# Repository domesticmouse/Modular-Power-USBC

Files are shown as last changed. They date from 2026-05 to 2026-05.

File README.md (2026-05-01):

# Modular-Power-USBC

## Project Overview
This project provides a compact, high-efficiency power solution for modular electronics (such as Eurorack synthesizers or analog prototyping boards). It converts standard **5V USB-C power** into clean, dual **±12V rails**.

### Key Features
- **USB-C Input:** Uses a power-only 6-pin receptacle for durability and simplicity.
- **Dual Rail Output:** Provides ±12V at up to 83mA per rail (2W total).
- **Comprehensive Protection:** Features overcurrent, reverse polarity, and back-drive protection.
- **Controlled Startup:** Integrated load switch with a physical toggle for safe power-up.
- **Indicator LEDs:** Visual confirmation for both positive and negative rails.

### Main Technologies
- **EDA Tool:** KiCad (Project files version 20260306, KiCad 10.0 or newer).
- **Major Components:**
  - **DC-DC Converter:** `A0512S-2WR2` (Isolated 2W module).
  - **Ideal Diode:** `LM66100` (Reverse polarity & back-drive protection).
  - **Load Switch:** `TPS22918` (Gated power control).
  - **Filtering:** Ferrite bead and 0805 SMD decoupling capacitors.
  - **Protection:** Resettable Polyfuse (`F1`).

## Circuit Architecture
The power path is designed for reliability and safety:

1.  **Input & Filtering:** 5V enters via `J1`. It is immediately protected by a Polyfuse and filtered by a Ferrite Bead to reduce high-frequency noise.
2.  **Polarity Protection:** An `LM66100` ideal diode provides extremely low-loss protection against reverse voltage on the input.
3.  **Gated Control:** The `TPS22918` load switch acts as the master gate. A physical SPDT slide switch (`SW1`) controls the enable pin, allowing the user to safely toggle the ±12V rails.
4.  **Isolated Conversion:** The `A0512S-2WR2` performs the heavy lifting, converting the 5V input to isolated ±12V outputs. This isolation helps prevent ground loops between the USB source and the analog circuitry.
5.  **Output Rail:** The dual rails are broken out to 2.54mm headers (`J2`, `J3`) for plugging into a breadboard.

## Directory Structure
- `Modular-Power-USBC.kicad_sch`: Main schematic file.
- `Modular-Power-USBC.kicad_pcb`: PCB layout file.
- `Modular-Power-USBC.pretty/`: Local footprint library for custom components.
- `ModularPower.kicad_sym`: Local symbol library.
- `production/`: Fabrication-ready files (Gerbers, BOM, Pick-and-Place).

## Project Status
- **Schematic:** Functional design complete.
- **ERC Status:** 1 Error (Pin 2 of PS1 not driven). Note: This is an ERC artifact due to a missing `PWR_FLAG` on the `GND` net; the electrical connection is correct.
- **Layout:** Complete.

## Building and Production
### KiCad Workflow
1. Open `Modular-Power-USBC.kicad_pro` in KiCad 10.0+.
2. Fabrication files are generated using the **KiCad Fabrication Toolkit** in the `production/` folder.
3. An **Interactive HTML BOM** is available in `bom/ibom.html` for hand-assembly.

## Development Conventions
- **Components:** Prefer LCSC part numbers (documented in `bom.csv` and component properties) for optimized sourcing via JLCPCB.
- **Footprints:** Custom footprints are maintained in the local `.pretty` library.

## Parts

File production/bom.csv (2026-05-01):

Designator | Footprint | Quantity | Value | LCSC Part #
C1, C2, C3, C6 | 0805 | 4 | 10uF | C6119887
C4, C5 | 0805 | 2 | 1uF | C116352
D1 | 0805 | 1 | RED | C84256
D2 | 0805 | 1 | BLUE | C84259
F1 | 0805 | 1 | Polyfuse | C22363531
FB1 | FerriteBead_0805_2012Metric_Pad1.20x1.40mm_HandSolder | 1 | FerriteBead | C76818
J1 | USB_C_Receptacle_HRO_TYPE-C-31-M-17 | 1 | USB_C_Receptacle_PowerOnly_6P | C668623
J2 | PinHeader_2x03_P2.54mm_Vertical | 1 | +12v Rail | C7501274
J3 | PinHeader_2x03_P2.54mm_Vertical | 1 | -12V Rail | C7501274
PS1 | Converter_DCDC_XP_POWER-IAxxxxS_THT | 1 | A0512S | C19272708
R1, R2, R5 | 0805 | 3 | 5k1Ω | C27834
R3, R4 | 0805 | 2 | 2k2Ω | C2907303
R6 | 0805 | 1 | 100Ω | C2907294
SW1 | SW_Slide_SPDT_Straight_CK_OS102011MS2Q | 1 | SW_SPDT | C2939725
U1 | SOT-363_SC-70-6 | 1 | LM66100 | C2869734
U2 | SOT-23-6 | 1 | TPS22918 | C131941

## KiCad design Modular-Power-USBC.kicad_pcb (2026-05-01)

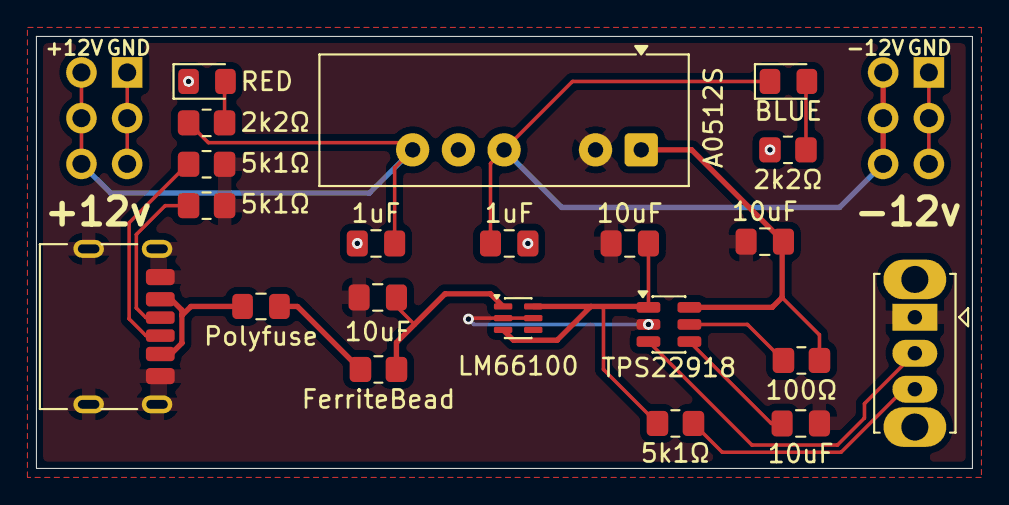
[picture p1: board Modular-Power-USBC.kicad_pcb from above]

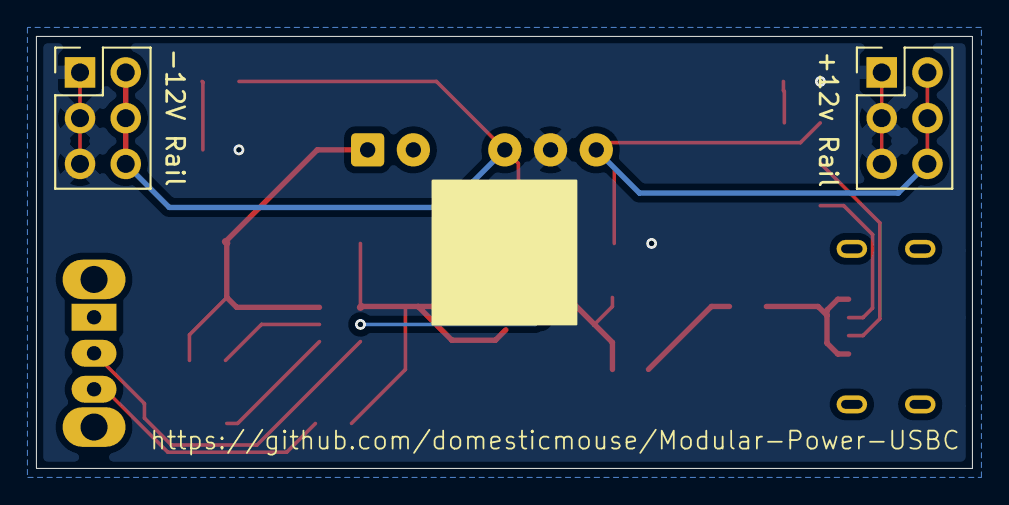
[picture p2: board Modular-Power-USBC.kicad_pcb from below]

Board: 2 copper layers, 52.0 x 24.0 mm, 23 parts (2 on the bottom side), 17 nets.

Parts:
C1, C2, C3, C6: 10uF; C_0805_2012Metric_Pad1.18x1.45mm_HandSolder
C4, C5: 1uF; C_0805_2012Metric_Pad1.18x1.45mm_HandSolder
D1: RED; LED_0805_2012Metric_Pad1.15x1.40mm_HandSolder
D2: BLUE; LED_0805_2012Metric_Pad1.15x1.40mm_HandSolder
F1: Polyfuse; Fuse_0805_2012Metric_Pad1.15x1.40mm_HandSolder
FB1: FerriteBead; FerriteBead_0805_2012Metric_Pad1.20x1.40mm_HandSolder
J1: USB_C_Receptacle_PowerOnly_6P; USB_C_Receptacle_HRO_TYPE-C-31-M-17
J2: +12v Rail; PinHeader_2x03_P2.54mm_Vertical
J3: -12V Rail; PinHeader_2x03_P2.54mm_Vertical
PS1: A0512S; Converter_DCDC_XP_POWER-IAxxxxS_THT
R1, R2, R5: 5k1Ω; R_0805_2012Metric_Pad1.20x1.40mm_HandSolder
R3, R4: 2k2Ω; R_0805_2012Metric_Pad1.20x1.40mm_HandSolder
R6: 100Ω; R_0805_2012Metric_Pad1.20x1.40mm_HandSolder
SW1: SW_SPDT; SW_Slide_SPDT_Straight_CK_OS102011MS2Q
U1: LM66100; SOT-363_SC-70-6
U2: TPS22918; SOT-23-6

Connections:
+5V: C3.1, PS1.1 (+Vin), R6.2, U2.6 (VOUT)
+12V: C4.1, J2.2, J2.4, J2.6, PS1.6 (+Vout), R3.1
-12V: C5.2, D2.1 (K), J3.2, J3.4, J3.6, PS1.4 (-Vout)
/CC1: J1.A5 (CC1), R2.1
/CC2: J1.B5 (CC2), R1.1
/VBUS: F1.1, J1.A9 (VBUS), J1.B9 (VBUS)
/VBUS_Protected: C2.1, R5.1, U1.3 (~CE), U1.6 (VOUT), U2.1 (VIN)
GND: C1.2, C2.2, C3.2, C6.2, J1.A12 (GND), J1.B12 (GND), J1.SH (SHIELD), PS1.2 (-Vin), R1.2, R2.2, SW1.1 (A), U1.2 (GND), U1.5 (ST), U2.2 (GND)
GNDA: C4.2, C5.1, D1.1 (K), J2.1, J2.3, J2.5, J3.1, J3.3, J3.5, PS1.5 (0V), R4.1
unnamed: D1.2 (A), R3.2
unnamed: D2.2 (A), R4.2
unnamed: F1.2, FB1.1
unnamed: SW1.2 (B), U2.3 (ON)
unnamed: R5.2, SW1.3 (C)
unnamed: C1.1, FB1.2, U1.1 (VIN)
unnamed: C6.1, U2.4 (CT)
unnamed: R6.1, U2.5 (QOD)

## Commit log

2026-04-30 Add switch
    [Modular-Power-USBC.kicad_pcb, Modular-Power-USBC.kicad_sch]
2026-04-30 Generate production files
    [Modular-Power-USBC.kicad_pcb, bom.csv, designators.csv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]
2026-04-30 Add README and fixup traces and symbols
    [Modular-Power-USBC.kicad_pcb, Modular-Power-USBC.kicad_sch]
2026-04-30 Drop redundant cap
    [Modular-Power-USBC.kicad_pcb, Modular-Power-USBC.kicad_sch]
2026-05-01 Clean up circuit with Gemini's assistance
    [Modular-Power-USBC.kicad_pcb, Modular-Power-USBC.kicad_sch]
2026-05-01 Add LCSC part numbers
    [Modular-Power-USBC.kicad_pcb, Modular-Power-USBC.kicad_sch, bom.csv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]
2026-05-01 Update for production
    [Modular-Power-USBC.kicad_pcb, Modular-Power-USBC.kicad_sch]
